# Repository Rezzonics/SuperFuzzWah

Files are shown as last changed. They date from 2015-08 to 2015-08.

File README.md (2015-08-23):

# SuperFuzzWah (Eagle 6.3.0)
Super Fuzz Wah guitar pedal (based on Shin-Ei Fuzz Wah / Univox SuperFuzz) Not a clone!!:

- Simulation (LTSpice Simulation Files)
  => GyratorWah 
  => SuperFuzzWah
- Eagle CAD files:
  => Schematics and BoM
  => PCB
  => Gerbers

Main features
- Germanium diodes replaced by Schottky diodes
- Inductor replaced by Gyrator circuit
- 9V DC voltage doubler ICL7660S

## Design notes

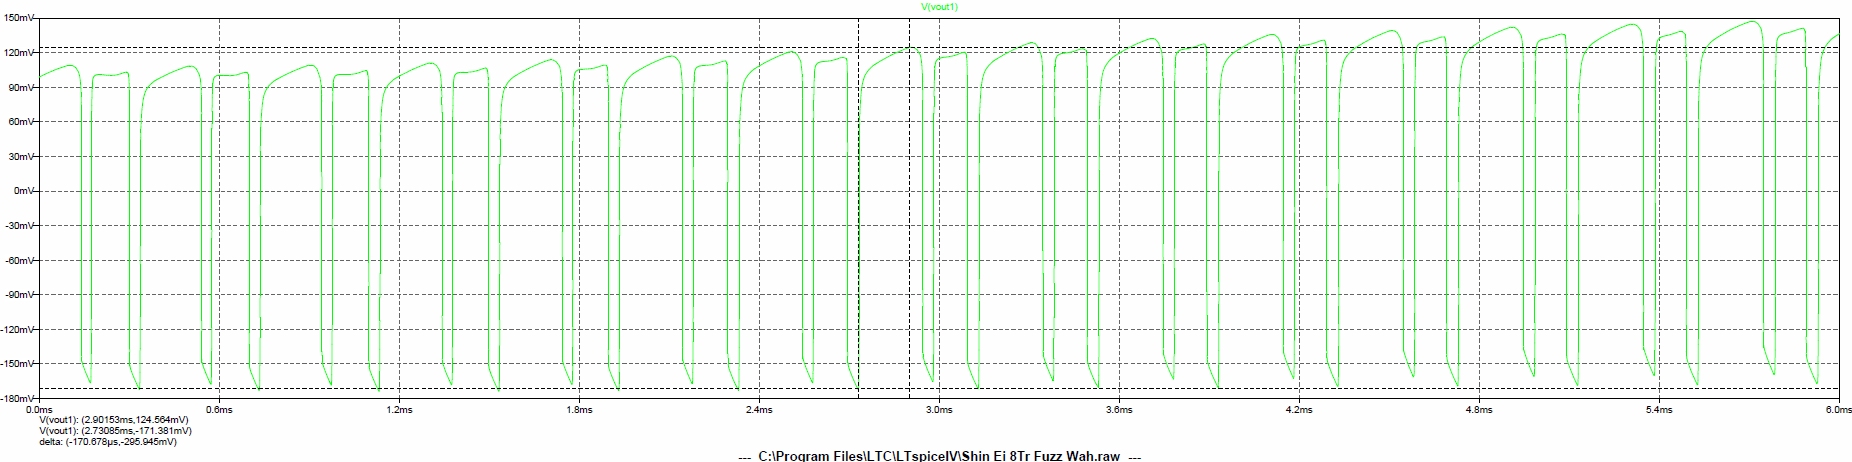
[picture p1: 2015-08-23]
Simulation/FuzzWah_LTSpice_V12.jpg

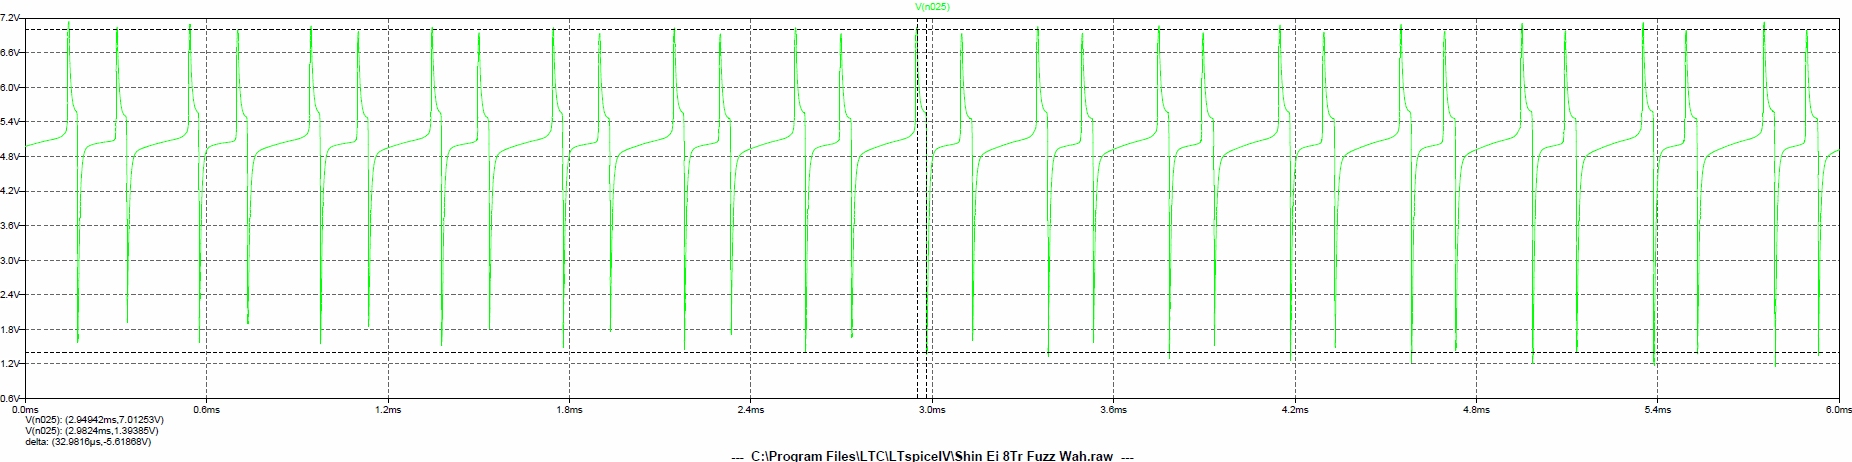
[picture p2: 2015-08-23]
Simulation/FuzzWah_LTSpice_V13_1.jpg

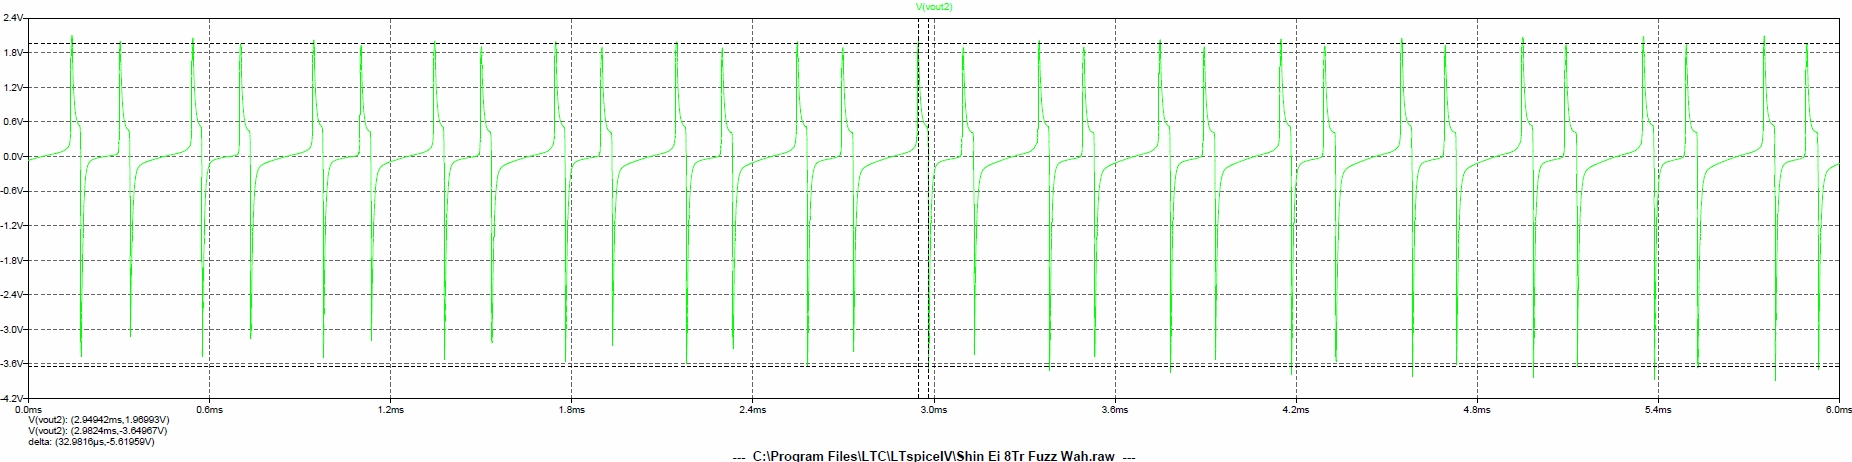
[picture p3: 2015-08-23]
Simulation/FuzzWah_LTSpice_V15.jpg

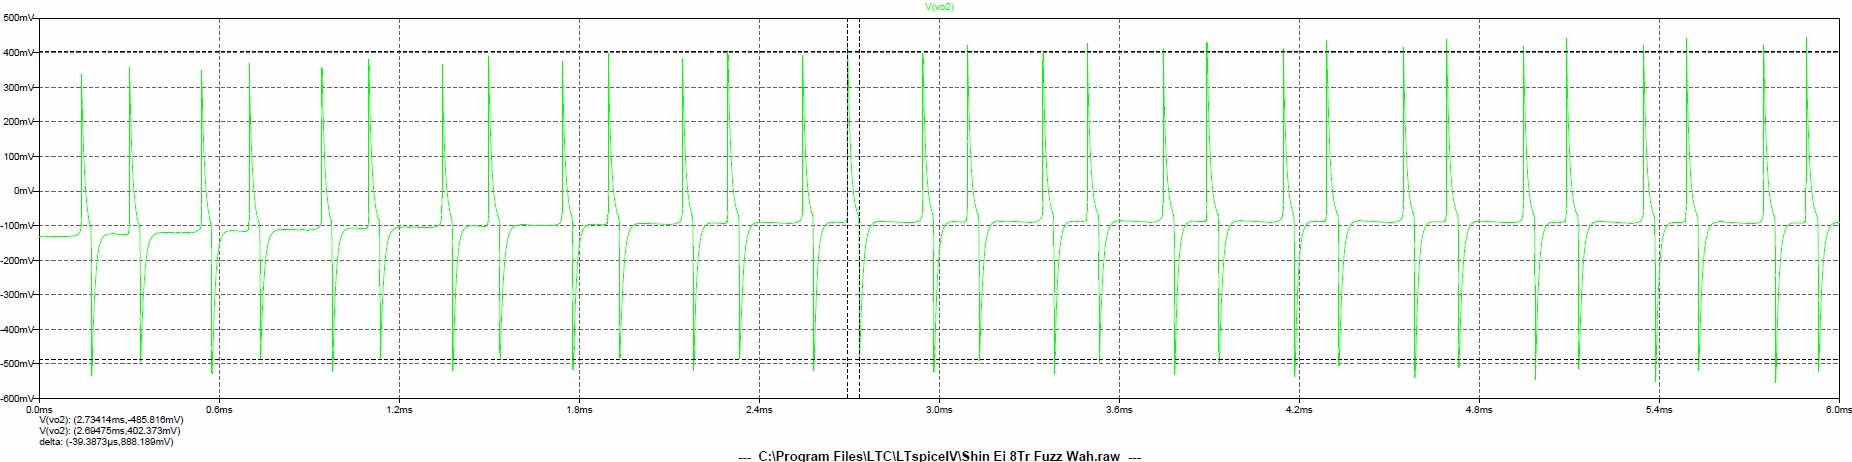
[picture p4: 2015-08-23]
Simulation/FuzzWah_LTSpice_V6.jpg

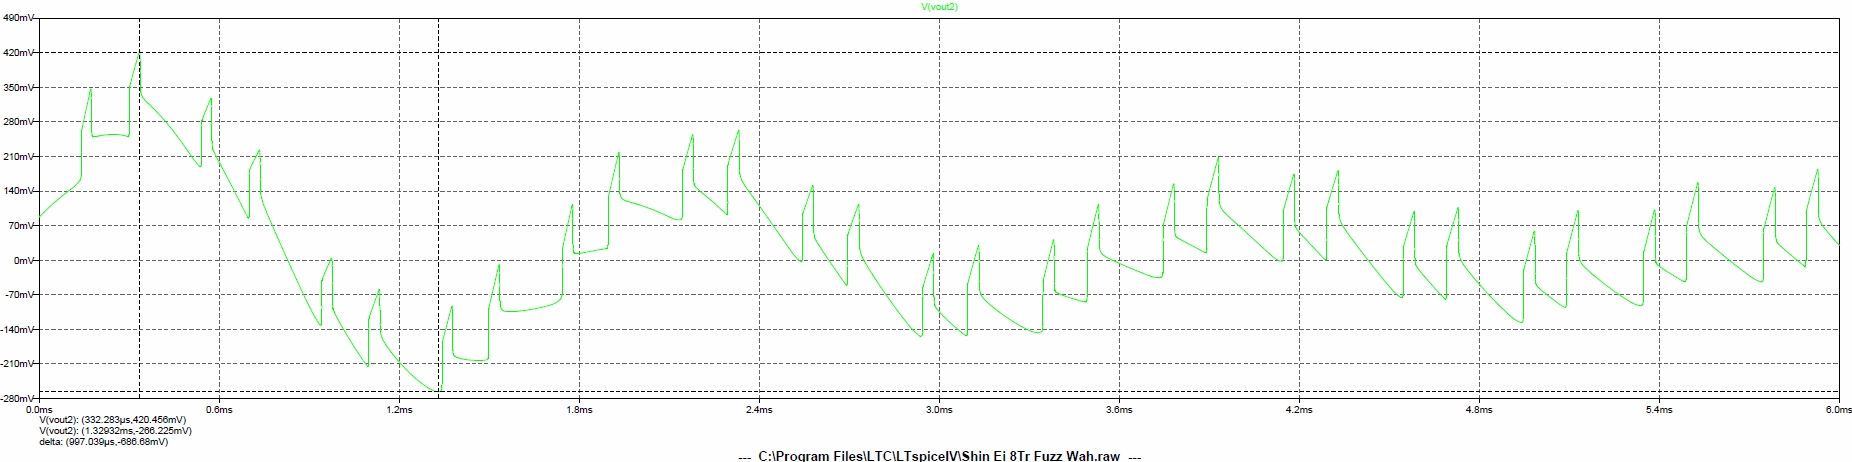
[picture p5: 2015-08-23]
Simulation/FuzzWah_LTSpice_V13_2.jpg

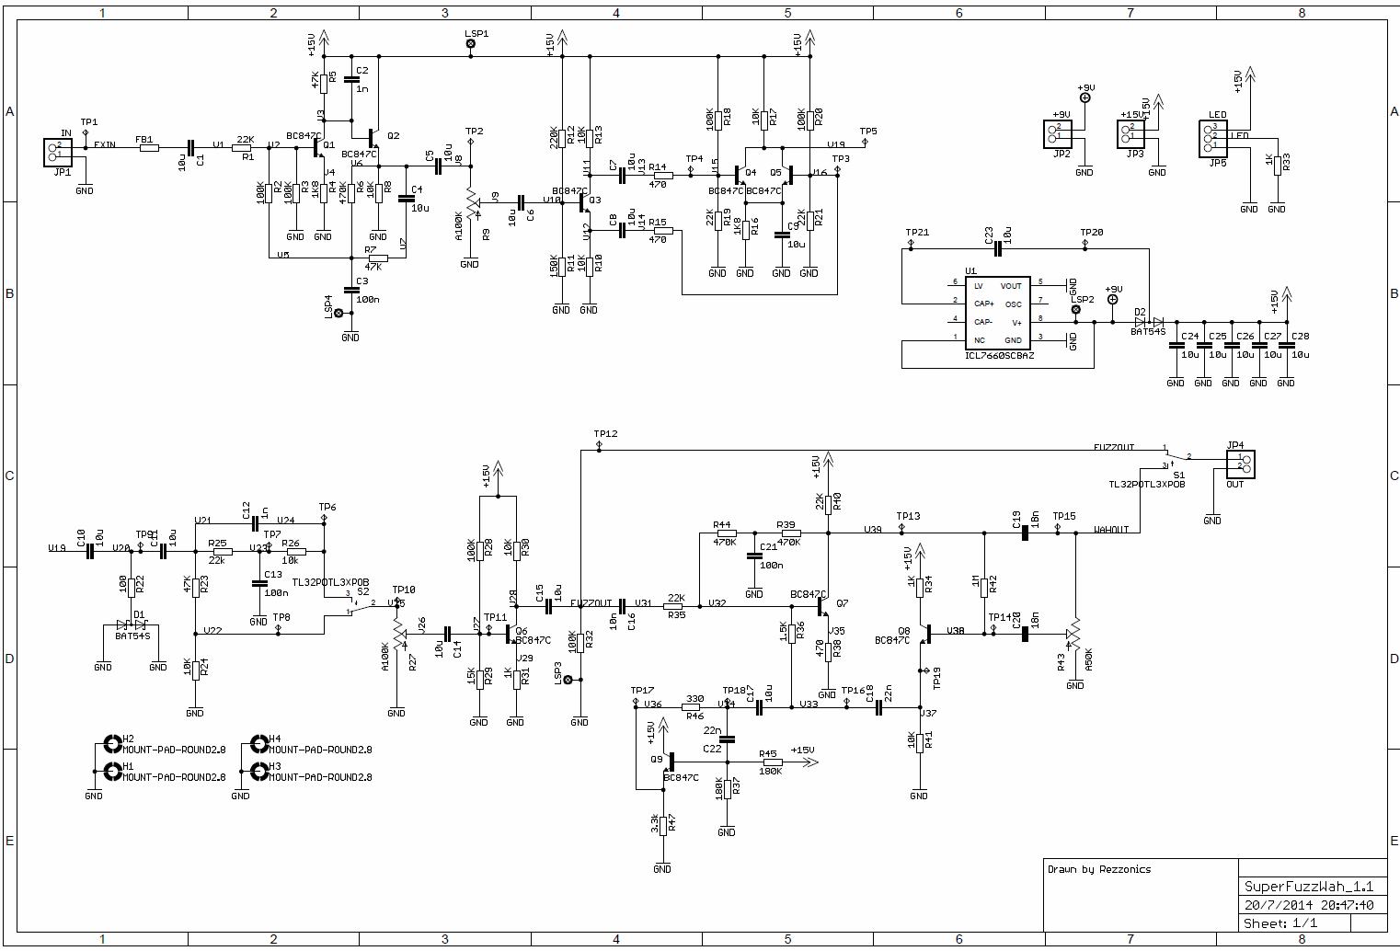
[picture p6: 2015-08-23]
SuperFuzzWah/SuperFuzz_1.1.sch.jpg

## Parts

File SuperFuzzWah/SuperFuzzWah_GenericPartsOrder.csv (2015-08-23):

Mfg Part Num | Mfg Name | VID | Vendor Part Num | Description | Customer Ref | Qty-1 | Qty-5 | Qty-25 | Part References | Value
BLM31PG121SN1L | Murata | ME | 81-BLM31PG121SN1L | EMI Filter Beads | Chokes & Arrays 1206 120 OHM | emi001 | 1 | 5 | 25 | FB1
77311-401-36LF | FCI | ME | 649-77311-401-36LF | Headers & Wire Housings 36P STR SR TMT HDR TIN .425IN LENGTH | con007 | 1 | 5 | 25 | JP2 | +9V
77311-401-36LF | FCI | ME | 649-77311-401-36LF | Headers & Wire Housings 36P STR SR TMT HDR TIN .425IN LENGTH | con007 | 1 | 5 | 25 | JP3 | +15V
ERJ-3EKF1501V | Panasonic | ME | 667-ERJ-3EKF1501V | Thick Film Resistors - SMD 0603 1.5Kohms 1% Tol | res055 | 1 | 5 | 25 | R36 | 1.5K
CR0603-FX-1001HLF | Bourns | ME | 652-CR0603-FX1001HLF | Thick Film Resistors - SMD 1KOHM 1/10WATT 1% | res001 | 3 | 15 | 75 | R31, R33, R34 | 1K
ERJ-3EKF1801V | Panasonic | ME | 667-ERJ-3EKF1801V | Thick Film Resistors - SMD 0603 1.8Kohms 1% Tol | res020 | 2 | 10 | 50 | R4, R16 | 1K8
CR0603-FX-1004ELF | Bourns | ME | 652-CR0603FX-1004ELF | Thick Film Resistors - SMD 1M 1% 1/10W | res003 | 1 | 5 | 25 | R42 | 1M
GRM1885C1H102FA01D | Murata | ME | 81-GRM1885C1H102FA1D | Multilayer Ceramic Capacitors MLCC - SMD/SMT 1000PF 50V 1% | capcer017 | 2 | 10 | 50 | C2, C12 | 1n
RK73H1JTTDD3321F | KOA Speer | ME | 660-RK73H1JTTDD3321F | Thick Film Resistors - SMD 1/10watts 3.32Kohms | res016 | 1 | 5 | 25 | R47 | 3.3k
CR0603-FX-1002HLF | Bourns | ME | 652-CR0603-FX1002HLF | Thick Film Resistors - SMD 10KOHM 1/10WATT 1% | res002 | 7 | 35 | 175 | R8, R10, R13, R17, R24, R30, R41 | 10K
CR0603-FX-1002HLF | Bourns | ME | 652-CR0603-FX1002HLF | Thick Film Resistors - SMD 10KOHM 1/10WATT 1% | res002 | 1 | 5 | 25 | R26 | 10k
ESD35C103K4T2A-18 | AVX | ME | 581-ESD35C103K4T2A18 | Multilayer Ceramic Capacitors MLCC - SMD/SMT 50volts 0.01uF 10% X7R 0603 SIZE | capcer029 | 1 | 5 | 25 | C16 | 10n
GRM21BR61E106KA73L | Murata | ME | 81-GRM21BR61E106KA3L | Multilayer Ceramic Capacitors MLCC - SMD/SMT 0805 X5R 25V 10uF | capcer020 | 18 | 90 | 450 | C1, C4, C5, C6, C7, C8, C9, C10, C11, C14, C15, C17, C23, C24, C25, C26, C27, C28 | 10u
RK73H1HTTC1502F | KOA Speer | ME | 660-RK73H1HTTC1502F | Thick Film Resistors - SMD 15K OHM 1% | res025 | 1 | 5 | 25 | R29 | 15K
ECH-U1H183GX5 | Panasonic | ME | 667-ECH-U1H183GX5 | Film Capacitors 0.018uF 50volts 2% 1210 PPS Film | capfilm015 | 2 | 10 | 50 | C19, C20 | 18n
ERJ-3EKF2202V | Panasonic | ME | 667-ERJ-3EKF2202V | Thick Film Resistors - SMD 0603 22Kohms 1% Tol | res056 | 5 | 25 | 125 | R1, R19, R21, R35, R40 | 22K
ERJ-3EKF2202V | Panasonic | ME | 667-ERJ-3EKF2202V | Thick Film Resistors - SMD 0603 22Kohms 1% Tol | res056 | 1 | 5 | 25 | R25 | 22k
ECH-U1H223JX5 | Panasonic | ME | 667-ECH-U1H223JX5 | Film Capacitors 0.022uF 50volts 5% 1210 PPS Film | capfilm014 | 2 | 10 | 50 | C18, C22 | 22n
RK73H1JTTD4702F | KOA Speer | ME | 660-RK73H1JTTD4702F | Thick Film Resistors - SMD 1/10watts 47Kohms 1% | res040 | 3 | 15 | 75 | R5, R7, R23 | 47K
CR0201-FW-1000GLF | Bourns | ME | 652-CR0201FW-1000GLF | Thick Film Resistors - SMD 100ohm 1% 250ppm | res014 | 1 | 5 | 25 | R22 | 100
CR0603-FX-1003ELF | Bourns | ME | 652-CR0603-FX-103ELF | Thick Film Resistors - SMD 100K 1% 1/10 WATT | res004 | 6 | 30 | 150 | R2, R3, R18, R20, R28, R32 | 100K
CB027D0104JBA | AVX | ME | 581-CB027D0104J | Film Capacitors 50vOLT 0.1uF 5% 1210 | capfilm002 | 3 | 15 | 75 | C3, C13, C21 | 100n
CRCW0603150KFKEB | Vishay | ME | 71-CRCW0603150KFKEB | Thick Film Resistors - SMD 1/10watt 150Kohms 1% | res049 | 1 | 5 | 25 | R11 | 150K
CR0603-FX-1803ELF | Bourns | ME | 652-CR0603FX-1803ELF | Thick Film Resistors - SMD 180K 1% 1/10W | res006 | 2 | 10 | 50 | R37, R45 | 180K
ERJ-3EKF2203V | Panasonic | ME | 667-ERJ-3EKF2203V | Thick Film Resistors - SMD 0603 220Kohms 1% Tol | res057 | 1 | 5 | 25 | R12 | 220K
ERJ-3EKF3300V | Panasonic | ME | 667-ERJ-3EKF3300V | Thick Film Resistors - SMD 0603 330ohms 1% Tol | res058 | 1 | 5 | 25 | R46 | 330
CR0603-FX-4700ELF | Bourns | ME | 652-CR0603FX-4700ELF | Thick Film Resistors - SMD 470 ohm 1% | res011 | 3 | 15 | 75 | R14, R15, R38 | 470
ERJ-3EKF4703V | Panasonic | ME | 667-ERJ-3EKF4703V | Thick Film Resistors - SMD 0603 470Kohms 1% Tol | res051 | 3 | 15 | 75 | R6, R39, R44 | 470K
RV16AF-10-20R1-A50K | Alpha (Taiwan) | ME | 31JA405-F | Potentiometers Audio 50K Solder Lugs | pot007 | 1 | 5 | 25 | R43 | A50K
RV16AF-10-20R1-A100K | Alpha (Taiwan) | ME | 31JA501-F | Potentiometers Audio 100K Solder Lugs | pot008 | 2 | 10 | 50 | R9, R27 | A100K
BAT54S | Fairchild Semiconductor | ME | 512-BAT54S | Schottky Diodes & Rectifiers 30V 200mA | diodes004 | 1 | 5 | 25 | D1 | BAT54S
BAT54S | Fairchild Semiconductor | ME | 512-BAT54S | Schottky Diodes & Rectifiers 30V 200mA | diodes004 | 1 | 5 | 25 | D2 | BAT54S
BC847C | 215 | NXP | ME | 771-BC847C-T/R | Transistors Bipolar - BJT NPN GP 100MA 45V | bjt004 | 9 | 45 | 225 | Q1, Q2, Q3, Q4, Q5, Q6, Q7, Q8, Q9 | BC847C
ICL7660CBAZ | Intersil | ME | 968-ICL7660CBAZ | Voltage Regulators - Switching Regulators CMOS VOLT CONVERTER 8 COM | icreg004 | 1 | 5 | 25 | U1 | ICL7660CSA
77311-401-36LF | FCI | ME | 649-77311-401-36LF | Headers & Wire Housings 36P STR SR TMT HDR TIN .425IN LENGTH | con007 | 1 | 5 | 25 | JP1 | IN
77311-401-36LF | FCI | ME | 649-77311-401-36LF | Headers & Wire Housings 36P STR SR TMT HDR TIN .425IN LENGTH | con007 | 1 | 5 | 25 | JP5 | LED
1249 | Keystone electronics | ME | 534-1249 | Test Points TP TERM BRS MATTE TINNED PLATED | tp001 | 4 | 20 | 100 | LSP1, LSP2, LSP3, LSP4 | LSP13
*** ERROR - PART '*' NOT FOUND FOR: "H1 | H2 | H3 | H4"
77311-401-36LF | FCI | ME | 649-77311-401-36LF | Headers & Wire Housings 36P STR SR TMT HDR TIN .425IN LENGTH | con007 | 1 | 5 | 25 | JP4 | OUT
M2012SS1W01 | NKK Switches | ME | 633-M201201 | Toggle Switches ON-NONE-ON SPDT | sw005 | 2 | 10 | 50 | S1, S2 | TL32POTL3XPOB
*** ERROR - PART '*' NOT FOUND FOR: "TP1 | TP2 | TP3 | TP4 | TP5 | TP6 | TP7 | TP8 | TP9 | TP10 | TP11 | TP12 | TP13 | TP14 | TP15 | TP16 | TP17 | TP18 | TP19 | TP20 | TP21"

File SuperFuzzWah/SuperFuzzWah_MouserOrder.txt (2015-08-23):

81-BLM31PG121SN1L|1
649-77311-401-36LF|1
649-77311-401-36LF|1
667-ERJ-3EKF1501V|1
652-CR0603-FX1001HLF|3
667-ERJ-3EKF1801V|2
652-CR0603FX-1004ELF|1
81-GRM1885C1H102FA1D|2
660-RK73H1JTTDD3321F|1
652-CR0603-FX1002HLF|7
652-CR0603-FX1002HLF|1
581-ESD35C103K4T2A18|1
81-GRM21BR61E106KA3L|18
660-RK73H1HTTC1502F|1
667-ECH-U1H183GX5|2
667-ERJ-3EKF2202V|5
667-ERJ-3EKF2202V|1
667-ECH-U1H223JX5|2
660-RK73H1JTTD4702F|3
652-CR0201FW-1000GLF|1
652-CR0603-FX-103ELF|6
581-CB027D0104J|3
71-CRCW0603150KFKEB|1
652-CR0603FX-1803ELF|2
667-ERJ-3EKF2203V|1
667-ERJ-3EKF3300V|1
652-CR0603FX-4700ELF|3
667-ERJ-3EKF4703V|3
31JA405-F|1
31JA501-F|2
512-BAT54S|1
512-BAT54S|1
771-BC847C-T/R|9
968-ICL7660CBAZ|1
649-77311-401-36LF|1
649-77311-401-36LF|1
534-1249|4
*|4 *** ERROR : H1/H2/H3/H4
649-77311-401-36LF|1
633-M201201|2
*|21 *** ERROR : TP1/TP2/TP3/TP4/TP5/TP6/TP7/TP8/TP9/TP10/TP11/TP12/TP13/TP14/TP15/TP16/TP17/TP18/TP19/TP20/TP21

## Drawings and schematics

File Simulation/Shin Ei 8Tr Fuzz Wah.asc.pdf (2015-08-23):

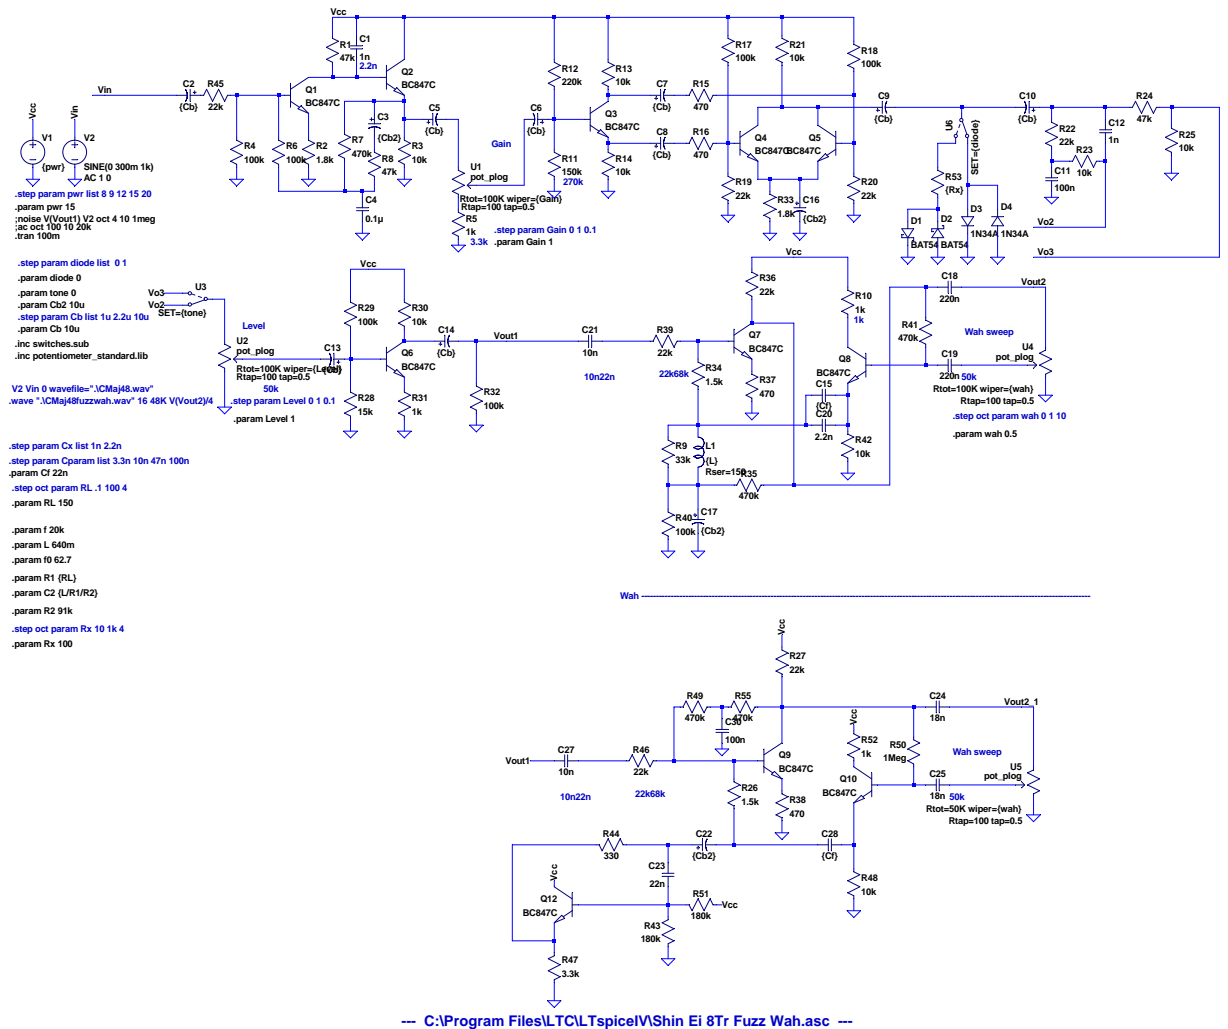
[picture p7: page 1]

.step param pwr list 8 9 12 15 20
.param pwr 15
;noise V(Vout1) V2 oct 4 10 1meg
;ac oct 100 10 20k
.tran 100m

.step param diode list 0 1
.param diode 0
.param tone 0
.param Cb2 10u
.step param Cb list 1u 2.2u 10u
.param Cb 10u
.inc switches.sub
.inc potentiometer_standard.lib

.step param Cx list 1n 2.2n
.step param Cparam list 3.3n 10n 47n 100n
.param Cf 22n
.step oct param RL .1 100 4
.param RL 150

--- C:\Program Files\LTC\LTspiceIV\Shin Ei 8Tr Fuzz Wah.asc ---

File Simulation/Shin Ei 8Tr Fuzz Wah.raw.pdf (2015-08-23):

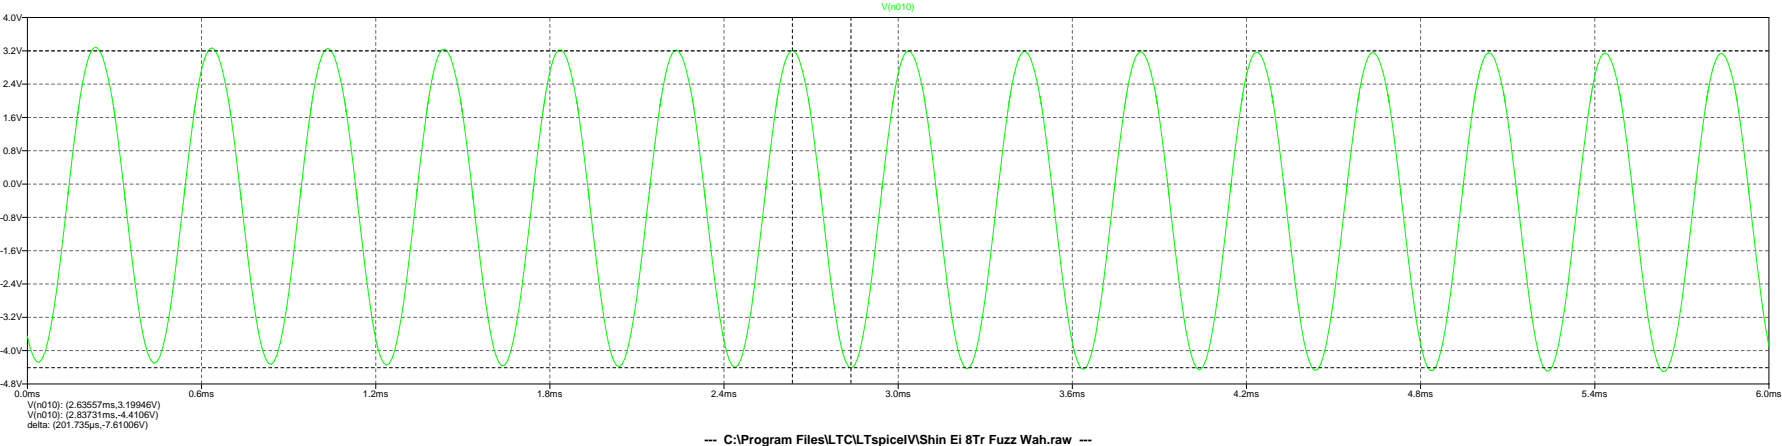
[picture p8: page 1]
V(n010): (2.63557ms,3.19946V) V(n010): (2.83731ms,-4.4106V) delta: (201.735µs,-7.61006V)

--- C:\Program Files\LTC\LTspiceIV\Shin Ei 8Tr Fuzz Wah.raw ---

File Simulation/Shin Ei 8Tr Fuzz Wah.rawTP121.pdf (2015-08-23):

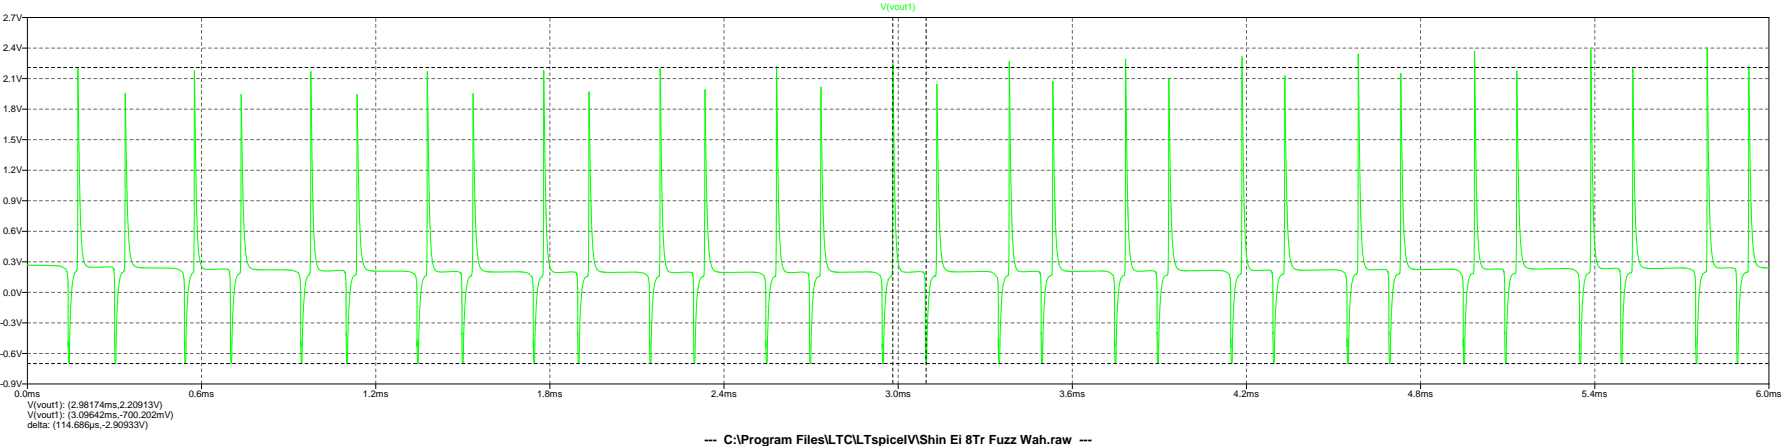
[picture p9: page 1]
V(vout1); V(vout1): (2.98174ms,2.20913V) V(vout1): (3.09642ms,-700.202mV) delta: (114.686µs,-2.90933V)

--- C:\Program Files\LTC\LTspiceIV\Shin Ei 8Tr Fuzz Wah.raw ---

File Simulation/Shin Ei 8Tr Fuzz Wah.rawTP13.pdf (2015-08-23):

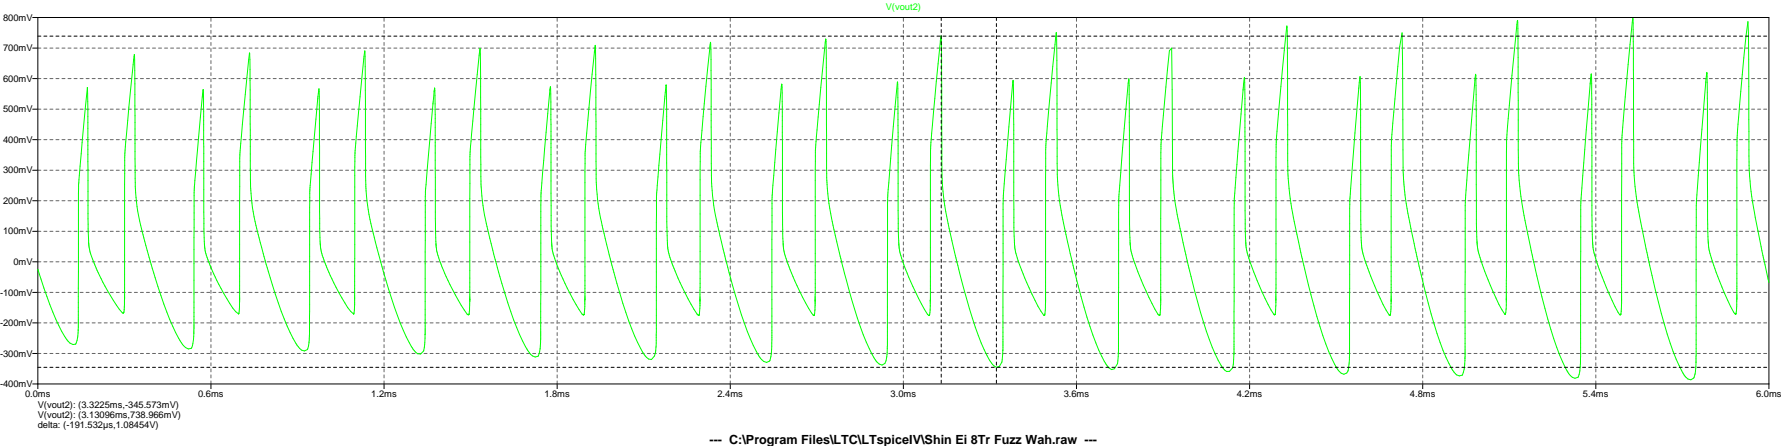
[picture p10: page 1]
V(vout2); V(vout2): (3.3225ms,-345.573mV) V(vout2): (3.13096ms,738.966mV) delta: (-191.532µs,1.08454V)

--- C:\Program Files\LTC\LTspiceIV\Shin Ei 8Tr Fuzz Wah.raw ---

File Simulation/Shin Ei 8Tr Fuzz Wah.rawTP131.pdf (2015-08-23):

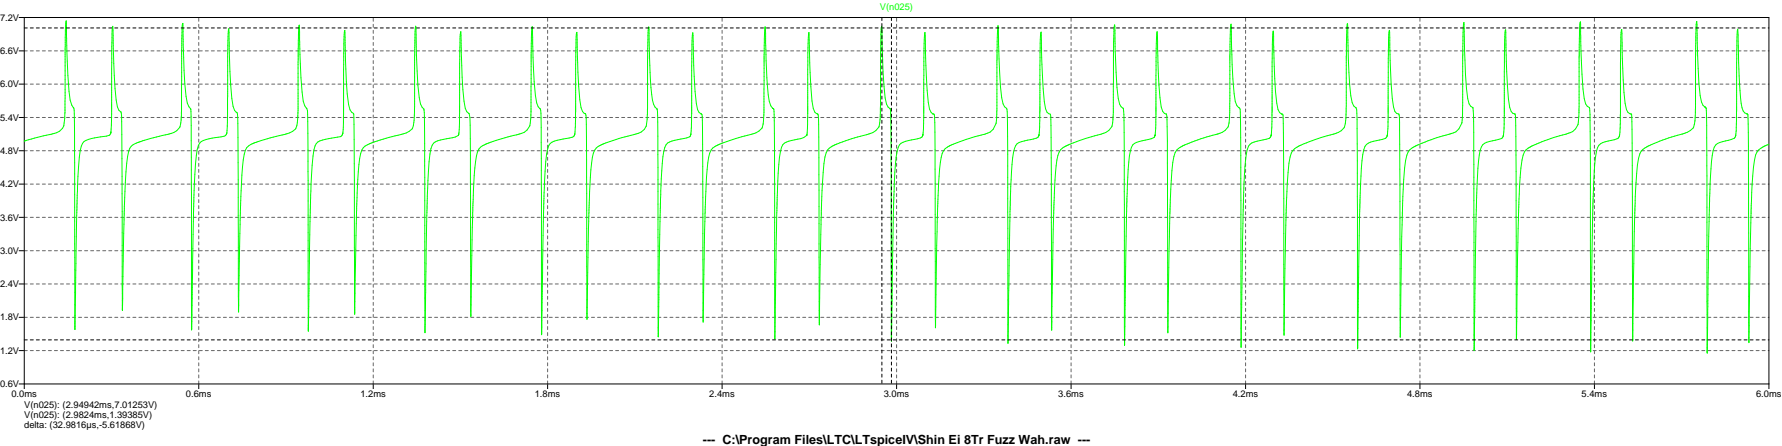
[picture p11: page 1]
V(n025): (2.94942ms,7.01253V) V(n025): (2.9824ms,1.39385V) delta: (32.9816µs,-5.61868V)

--- C:\Program Files\LTC\LTspiceIV\Shin Ei 8Tr Fuzz Wah.raw ---

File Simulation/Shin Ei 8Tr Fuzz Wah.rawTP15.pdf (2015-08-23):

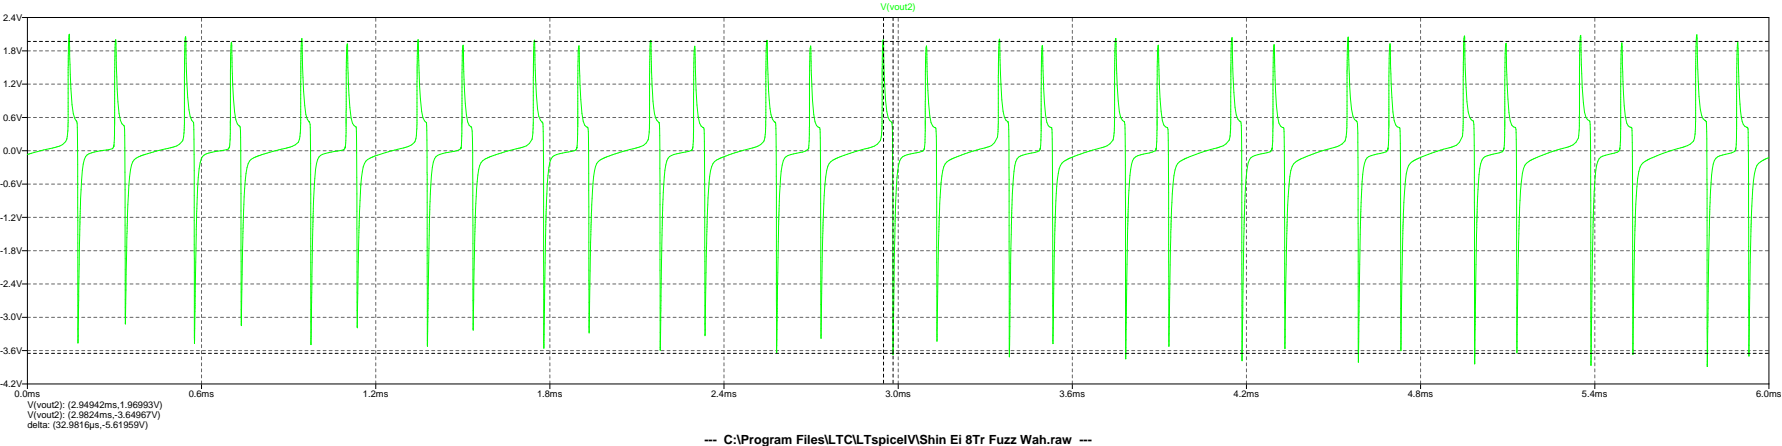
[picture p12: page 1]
V(vout2); V(vout2): (2.94942ms,1.96993V) V(vout2): (2.9824ms,-3.64967V) delta: (32.9816µs,-5.61959V)

--- C:\Program Files\LTC\LTspiceIV\Shin Ei 8Tr Fuzz Wah.raw ---

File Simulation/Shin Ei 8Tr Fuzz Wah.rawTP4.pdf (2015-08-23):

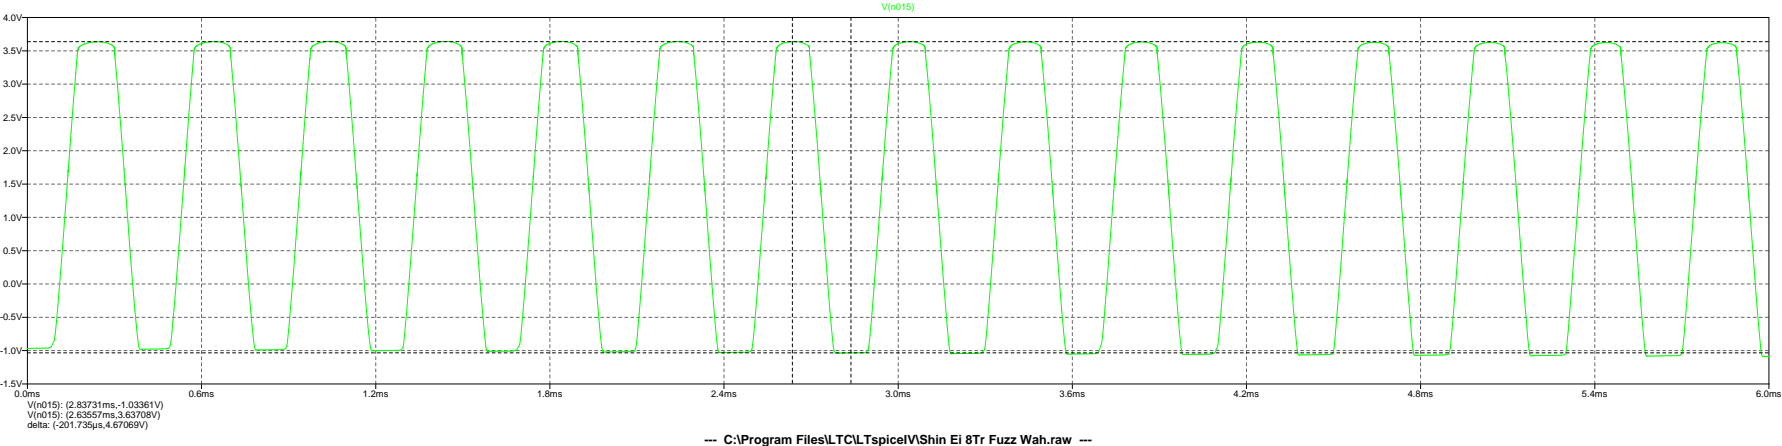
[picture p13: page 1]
V(n015): (2.83731ms,-1.03361V) V(n015): (2.63557ms,3.63708V) delta: (-201.735µs,4.67069V)

--- C:\Program Files\LTC\LTspiceIV\Shin Ei 8Tr Fuzz Wah.raw ---

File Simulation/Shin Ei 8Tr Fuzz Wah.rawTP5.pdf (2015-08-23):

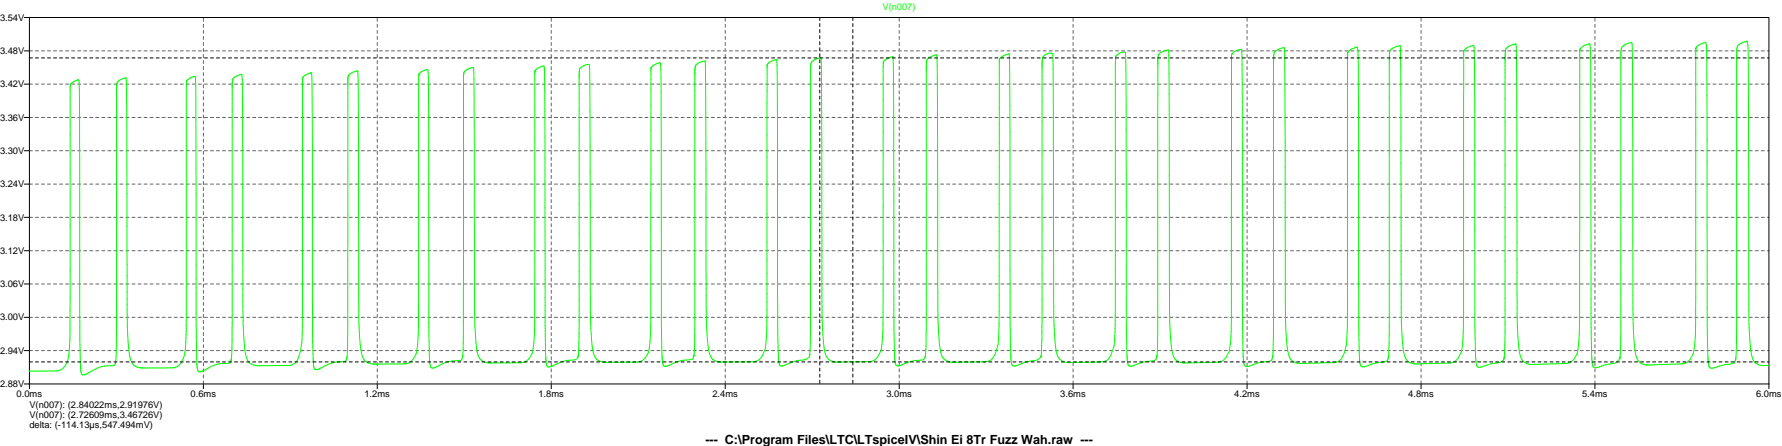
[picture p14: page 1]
V(n007): (2.84022ms,2.91976V) V(n007): (2.72609ms,3.46726V) delta: (-114.13µs,547.494mV)

--- C:\Program Files\LTC\LTspiceIV\Shin Ei 8Tr Fuzz Wah.raw ---

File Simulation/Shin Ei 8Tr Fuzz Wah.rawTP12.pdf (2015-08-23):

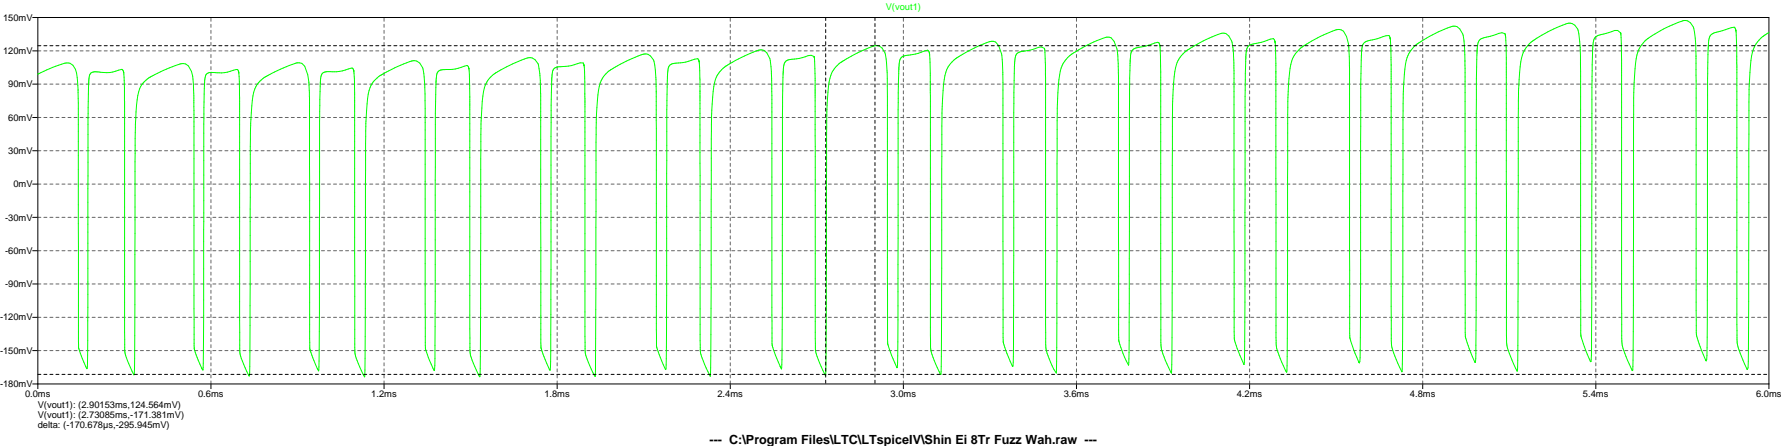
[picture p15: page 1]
V(vout1); V(vout1): (2.90153ms,124.564mV) V(vout1): (2.73085ms,-171.381mV) delta: (-170.678µs,-295.945mV)

--- C:\Program Files\LTC\LTspiceIV\Shin Ei 8Tr Fuzz Wah.raw ---

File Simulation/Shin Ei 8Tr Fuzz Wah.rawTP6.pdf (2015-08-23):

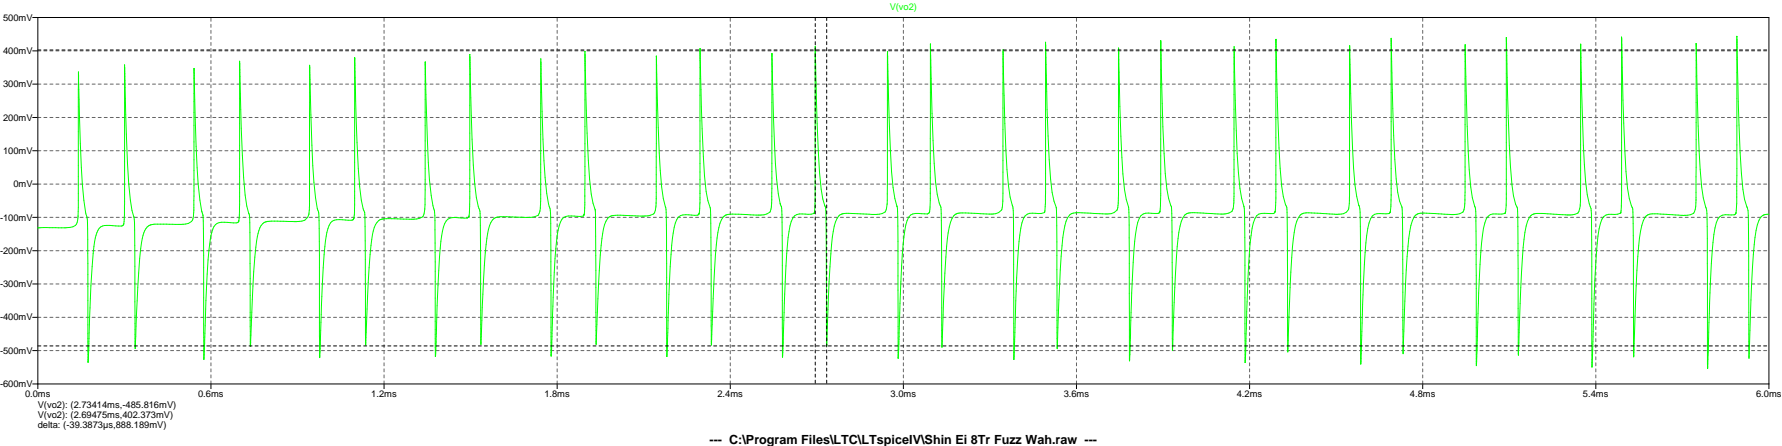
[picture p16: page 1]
V(vo2): (2.73414ms,-485.816mV) V(vo2): (2.69475ms,402.373mV) delta: (-39.3873µs,888.189mV)

--- C:\Program Files\LTC\LTspiceIV\Shin Ei 8Tr Fuzz Wah.raw ---

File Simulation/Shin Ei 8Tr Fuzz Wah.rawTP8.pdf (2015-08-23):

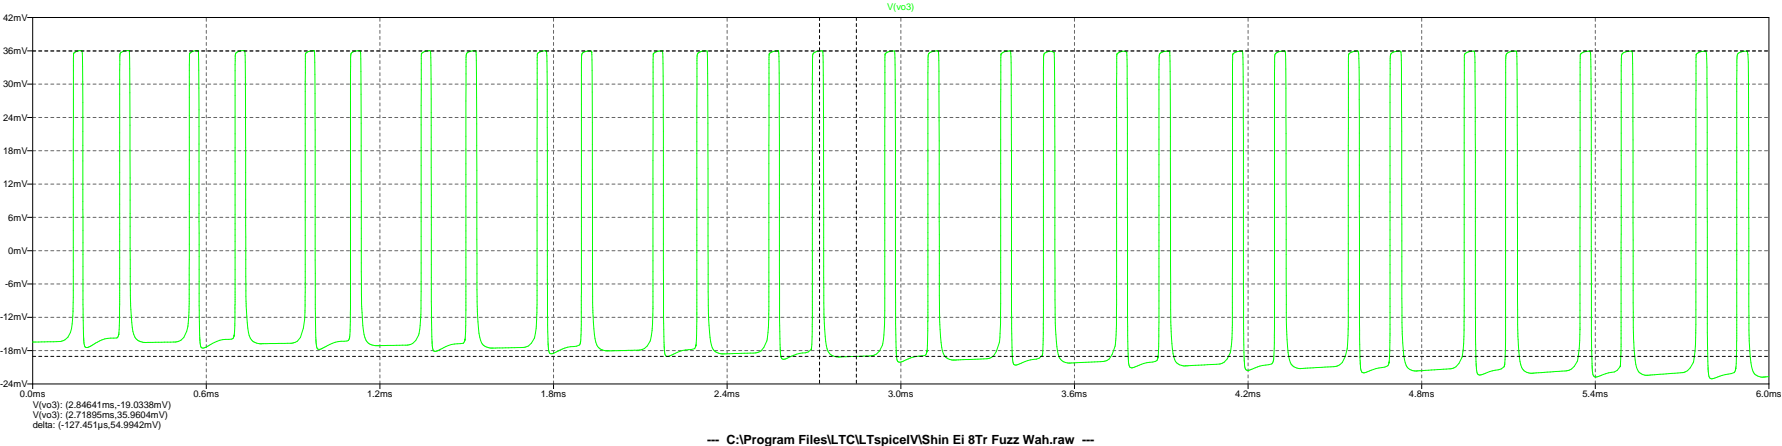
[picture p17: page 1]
V(vo3): (2.84641ms,-19.0338mV) V(vo3): (2.71895ms,35.9604mV) delta: (-127.451µs,54.9942mV)

--- C:\Program Files\LTC\LTspiceIV\Shin Ei 8Tr Fuzz Wah.raw ---

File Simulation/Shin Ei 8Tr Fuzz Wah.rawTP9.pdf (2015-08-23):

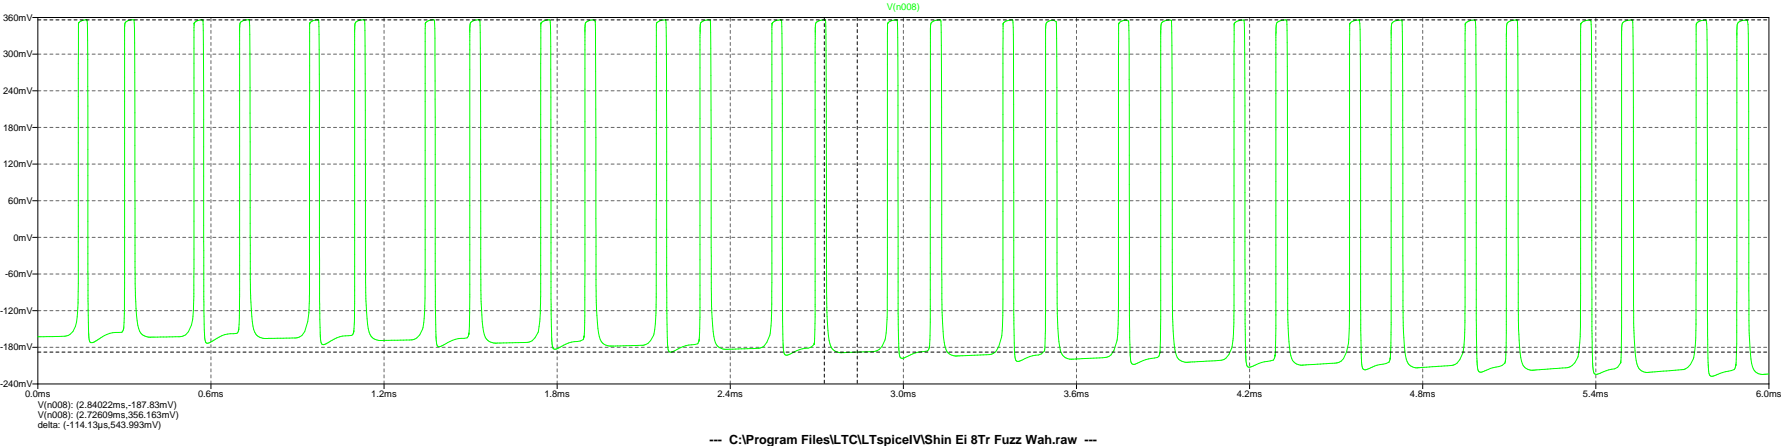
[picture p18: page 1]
V(n008): (2.84022ms,-187.83mV) V(n008): (2.72609ms,356.163mV) delta: (-114.13µs,543.993mV)

--- C:\Program Files\LTC\LTspiceIV\Shin Ei 8Tr Fuzz Wah.raw ---

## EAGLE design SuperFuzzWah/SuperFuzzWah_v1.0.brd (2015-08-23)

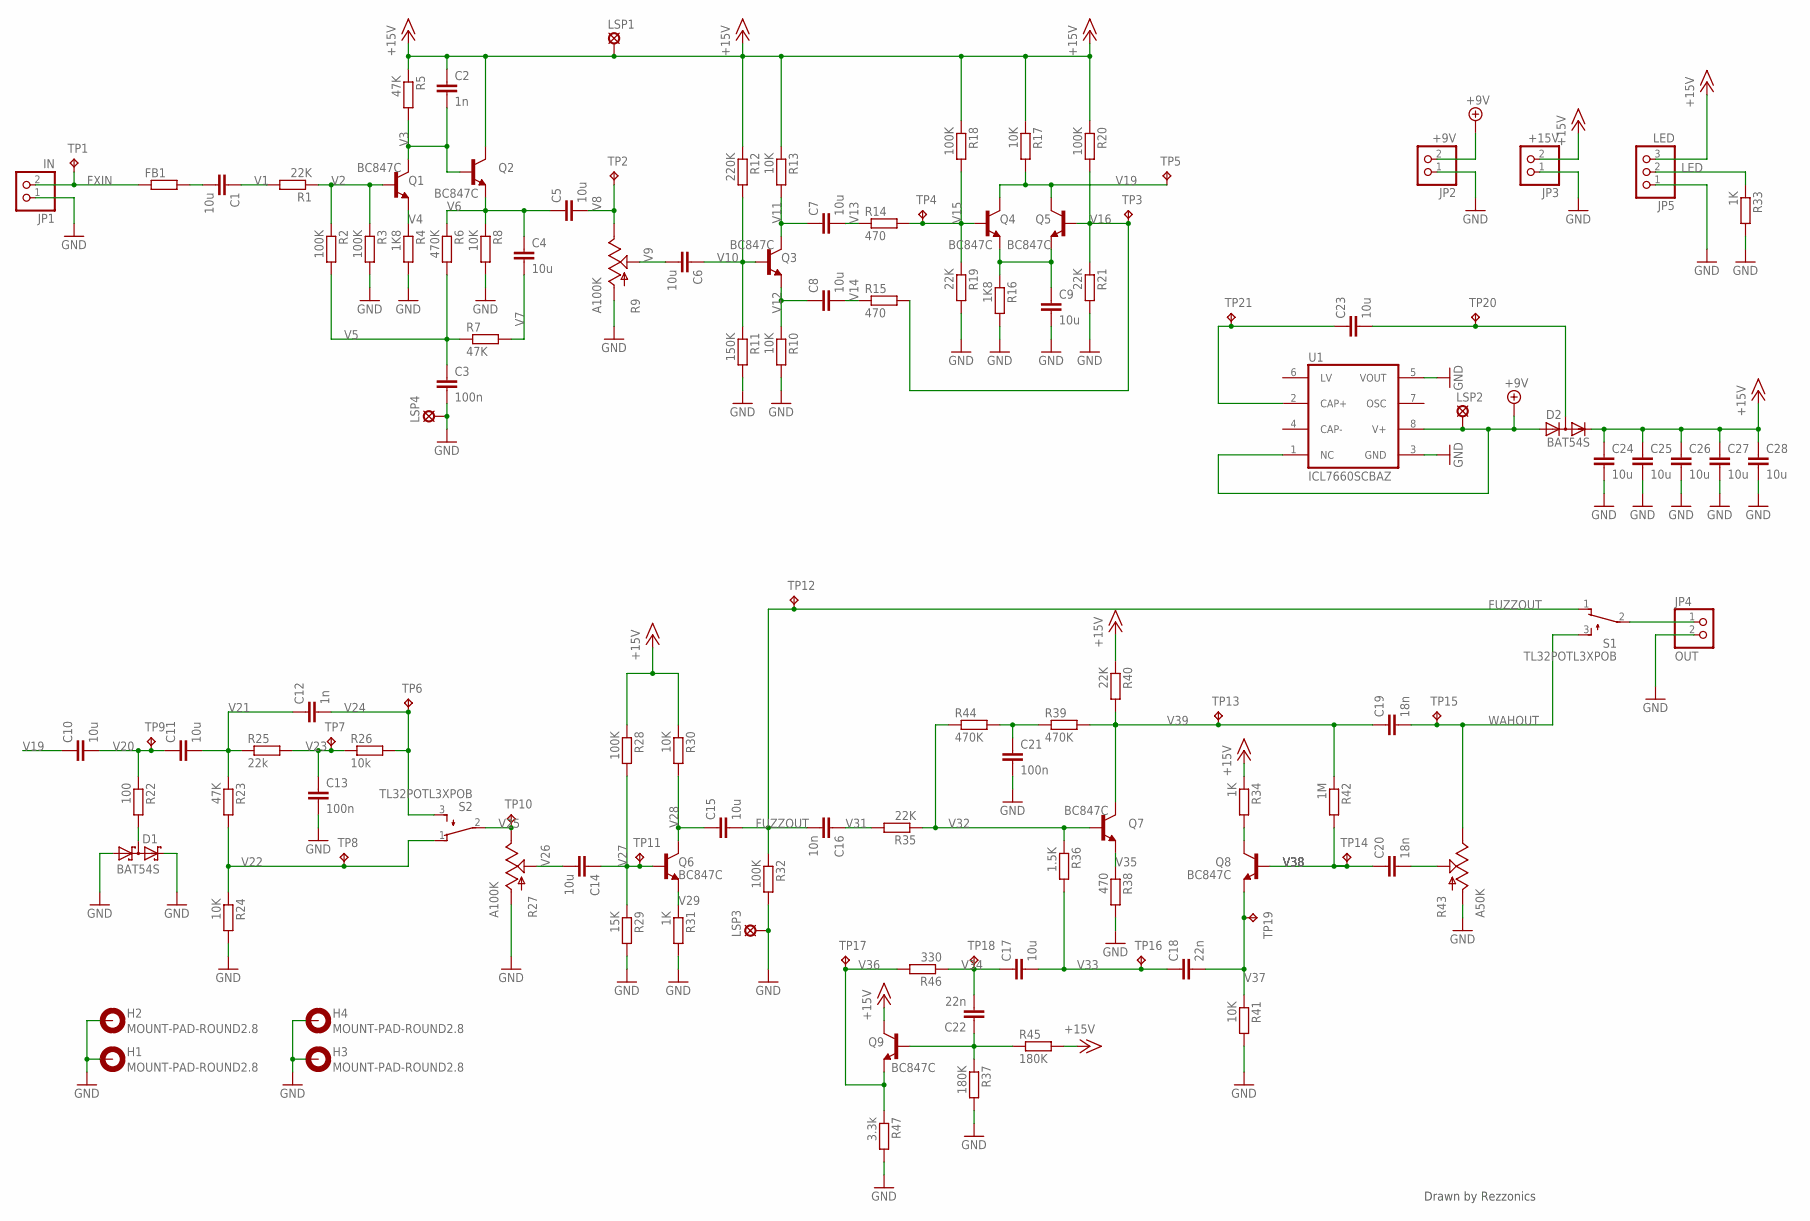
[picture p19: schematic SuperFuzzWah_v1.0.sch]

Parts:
C1, C4, C5, C6, C7, C8, C9, C10, C11, C14, C15, C17, C23, C24, C25, C26, C27, C28: 10u; C0805K; MPN GRM21BR61E106KA73L
C2, C12: 1n; C0805K; MPN GRM1885C1H102FA01D
C3, C13, C21: 100n; C1210K; MPN CB027D0104JBA
C16: 10n; C0603K; MPN ESD35C103K4T2A-18
C18, C22: 22n; C1210K; MPN ECH-U1H223JX5
C19, C20: 18n; C1210K; MPN ECH-U1H183GX5
D1, D2: BAT54S; SOT23; MPN BAT54S
FB1: R-EU_R1206; R1206; MPN BLM31PG121SN1L
H1, H2, H3, H4: MOUNT-PAD-ROUND2.8; 2,8-PAD; MPN *
JP1: IN; 1X02; MPN 77311-401-36LF
JP2: +9V; 1X02; MPN 77311-401-36LF
JP3: +15V; 1X02; MPN 77311-401-36LF
JP4: OUT; 1X02; MPN 77311-401-36LF
JP5: LED; 1X03; MPN 77311-401-36LF
LSP1, LSP2, LSP3, LSP4: LSP13; MPN 1249
Q1, Q2, Q3, Q4, Q5, Q6, Q7, Q8, Q9: BC847C; SOT23-BEC; MPN BC847C,215
R1, R19, R21, R35, R40: 22K; R0603; MPN ERJ-3EKF2202V
R2, R3, R18, R20, R28, R32: 100K; R0603; MPN CR0603-FX-1003ELF
R4, R16: 1K8; R0603; MPN ERJ-3EKF1801V
R5, R7, R23: 47K; R0603; MPN RK73H1JTTD4702F
R6, R39, R44: 470K; R0603; MPN ERJ-3EKF4703V
R8, R10, R13, R17, R24, R30, R41: 10K; R0603; MPN CR0603-FX-1002HLF
R9, R27: A100K; POT_ALPHA_RV16AF-20; MPN RV16AF-10-20R1-A100K
R11: 150K; R0603; MPN CRCW0603150KFKEB
R12: 220K; R0603; MPN ERJ-3EKF2203V
R14, R15, R38: 470; R0603; MPN CR0603-FX-4700ELF
R22: 100; R0603; MPN CR0201-FW-1000GLF
R25: 22k; R0603; MPN ERJ-3EKF2202V
R26: 10k; R0603; MPN CR0603-FX-1002HLF
R29: 15K; R0603; MPN RK73H1HTTC1502F
R31, R33, R34: 1K; R0603; MPN CR0603-FX-1001HLF
R36: 1.5K; R0603; MPN ERJ-3EKF1501V
R37, R45: 180K; R0603; MPN CR0603-FX-1803ELF
R42: 1M; R0603; MPN CR0603-FX-1004ELF
R43: A50K; POT_ALPHA_RV16AF-20; MPN RV16AF-10-20R1-A50K
R46: 330; R0603; MPN ERJ-3EKF3300V
R47: 3.3k; R0603; MPN RK73H1JTTDD3321F
S1, S2: TL32POTL3XPOB; TL3XPOB; MPN M2012SS1W01
TP1, TP2, TP3, TP4, TP5, TP6, TP7, TP8, TP9, TP10, TP11, TP12, TP13, TP14, TP15, TP16, TP17, TP18, TP19, TP20, TP21: TPTP10R; TP10R; MPN *
U1: ICL7660SCBAZ; SO08; MPN ICL7660SCBAZ

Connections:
+9V: D2.1 (A), JP2.2, LSP2.MP, U1.1 (NC), U1.8 (V+)
+15V: C2.1, C24.1, C25.1, C26.1, C27.1, C28.1, D2.2 (C), JP3.2, JP5.3, LSP1.MP, Q2.C, Q9.C, R5.1, R12.1, R13.1, R17.1, R18.1, R20.1, R28.1, R30.1, R34.1, R40.1, R45.2
FUZZOUT: C15.2, C16.2, R32.1, S1.1 (O), TP12.TP
FXIN: FB1.1, JP1.2, TP1.TP
GND: C3.2, C9.2, C13.2, C21.2, C24.2, C25.2, C26.2, C27.2, C28.2, D1.1 (A1), D1.2 (C2), H1.B2,8, H2.B2,8, H3.B2,8, H4.B2,8, JP1.1, JP2.1, JP3.1, JP4.2, JP5.1, LSP3.MP, LSP4.MP, R3.2, R4.2, R8.2, R9.1 (A), R10.2, R11.2, R16.2, R19.2, R21.2, R24.2, R27.1 (A), R29.2, R31.2, R32.2, R33.2, R37.2, R38.2, R41.2, R43.1 (A), R47.2, U1.3 (GND), U1.5 (VOUT)
LED: JP5.2, R33.1
unnamed: D1.3 (C1A2), R22.2
unnamed: C20.2, R43.2 (S)
unnamed: C21.1, R39.1, R44.2
unnamed: Q8.C, R34.2
unnamed: JP4.1, S1.2
unnamed: C22.1, Q9.B, R37.1, R45.1
unnamed: C1.2, FB1.2
unnamed: C23.1, TP21.TP, U1.2 (CAP+)
unnamed: C23.2, D2.3 (AC), TP20.TP
unnamed: C9.1, Q4.E, Q5.E, R16.1
V1: C1.1, R1.2
V2: Q1.B, R1.1, R2.1, R3.1
V3: C2.2, Q1.C, Q2.B, R5.2
V4: Q1.E, R4.1
V5: C3.1, R2.2, R6.2, R7.1
V6: C4.1, C5.1, Q2.E, R6.1, R8.1
V7: C4.2, R7.2
V8: C5.2, R9.3 (E), TP2.TP
V9: C6.2, R9.2 (S)
V10: C6.1, Q3.B, R11.1, R12.2
V11: C7.1, Q3.C, R13.2
V12: C8.1, Q3.E, R10.1
V13: C7.2, R14.1
V14: C8.2, R15.1
V15: Q4.B, R14.2, R18.2, R19.1, TP4.TP
V16: Q5.B, R15.2, R20.2, R21.1, TP3.TP
V19: C10.1, Q4.C, Q5.C, R17.2, TP5.TP
V20: C10.2, C11.1, R22.1, TP9.TP
V21: C11.2, C12.1, R23.1, R25.1
V22: R23.2, R24.1, S2.1 (O), TP8.TP
V23: C13.1, R25.2, R26.1, TP7.TP
V24: C12.2, R26.2, S2.3 (S), TP6.TP
V25: R27.3 (E), S2.2, TP10.TP
V26: C14.2, R27.2 (S)
V27: C14.1, Q6.B, R28.2, R29.1, TP11.TP
V28: C15.1, Q6.C, R30.2
V29: Q6.E, R31.1
V31: C16.1, R35.2
V32: Q7.B, R35.1, R36.1, R44.1
V33: C17.2, C18.1, R36.2, TP16.TP
V34: C17.1, C22.2, R46.1, TP18.TP
V35: Q7.E, R38.1
V36: Q9.E, R46.2, R47.1, TP17.TP
V37: C18.2, Q8.E, R41.1, TP19.TP
V38: C20.1, Q8.B, R42.2, TP14.TP
V39: C19.1, Q7.C, R39.2, R40.2, R42.1, TP13.TP
WAHOUT: C19.2, R43.3 (E), S1.3 (S), TP15.TP

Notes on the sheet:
Drawn by Rezzonics

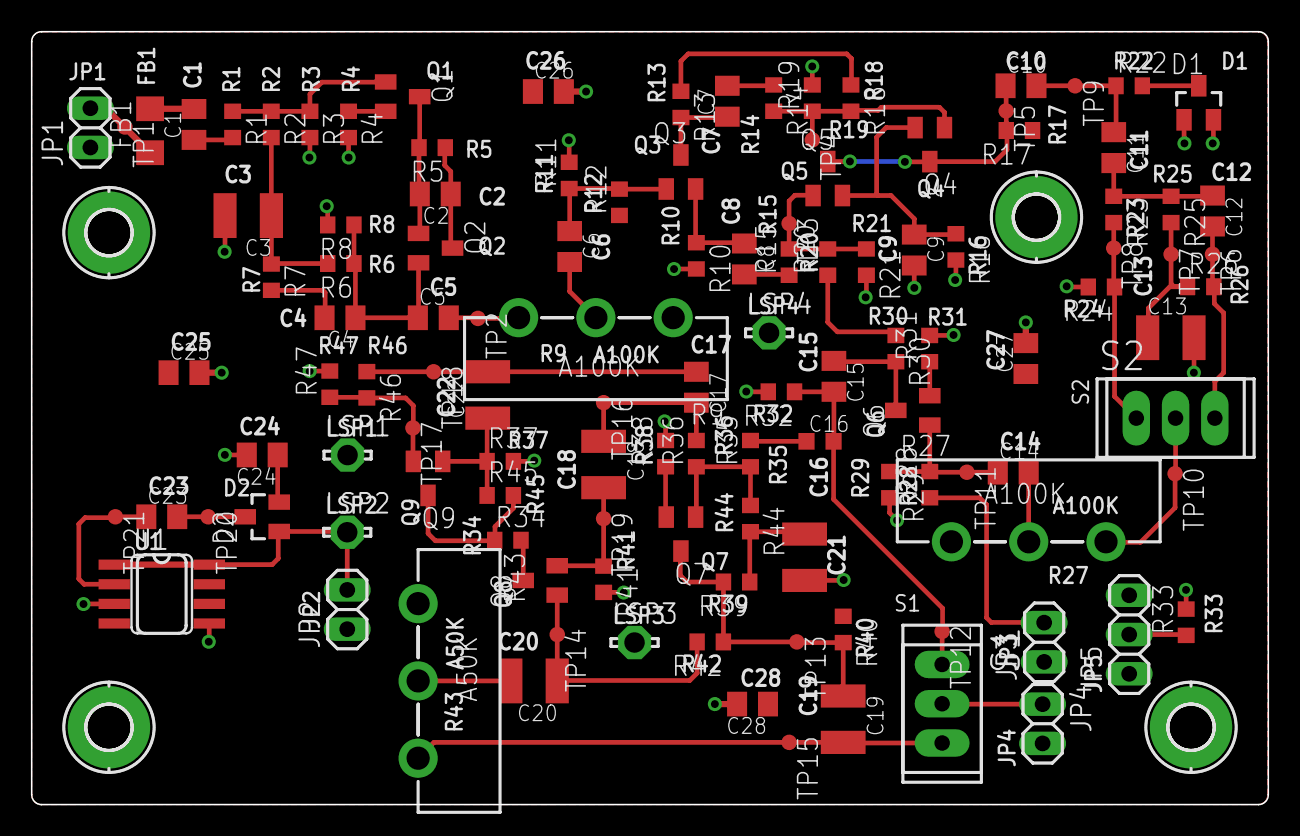
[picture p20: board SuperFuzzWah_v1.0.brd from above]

Board: 2 copper layers, 80.0 x 50.0 mm, 124 parts (0 on the bottom side), 53 nets.

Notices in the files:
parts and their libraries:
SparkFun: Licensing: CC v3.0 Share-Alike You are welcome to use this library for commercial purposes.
